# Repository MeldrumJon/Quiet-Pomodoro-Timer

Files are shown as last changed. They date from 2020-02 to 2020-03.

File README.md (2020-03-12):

# Visual-Timer

Shows timer progress on screen.  Flashes a bright LED when the timer expires 
instead of ringing or vibrating.  Useful for time management in quiet offices 
or libraries.

Visual Timer
Time's Up

## Parts

- [16x2 Reflective LCD Character Display](https://www.mouser.com/ProductDetail/668-S16204XRGHS10B)
- ATMega328p-PU
    - With fuses set to use internal 8MHz clock (use Makefile: `make fuses`)
- [Rotary encoder with push button switch](https://www.mouser.com/ProductDetail/652-PEC11R4315KS0012)
- 2x [Bright LEDs](https://www.mouser.com/ProductDetail/78-TLHK46Q1R2)
- 10uF electrolytic capacitor
- 3x 0.1uF ceramic capacitors
- 2x 220 ohm resistors
- 10k ohm potentiometer
- Breakaway headers
- Battery holder for 3xAA or 3xAAA batteries

## Tools

- AVR ISP Programmer or [arduinoISP](https://www.arduino.cc/en/tutorial/arduinoISP)
- USB to TTY serial adapter for debugging.

## Schematic

Visual Timer's schematic

## Setup

1. Install the AVR-GCC toolchain (and update your `PATH` variable, if necessary)
2. Connect the AVR ISP programmer pins to the ISP header on the PCB.
3. Connect the ATMega328p's TX pin to RX on the TTY serial adapter (optional)
4. Update the `program` and `fuses` recipes in the makefile to use your AVR 
ISP programmer.
5. Update the `serial` recipe in the makefile to use your USB to TTY serial 
adapter.
6. Run `make fuses` to set the fuses on the ATMega328p.
    - If the ATMega328p was previously set to use an external clock or crystal 
    oscillator, an external clock or crystal oscillator will be needed to set 
    the fuses.

## Programming

Run `make program` to program the ATMega328p.

## PCB

KiCAD files are in [the `hardware` Folder](./hardware).

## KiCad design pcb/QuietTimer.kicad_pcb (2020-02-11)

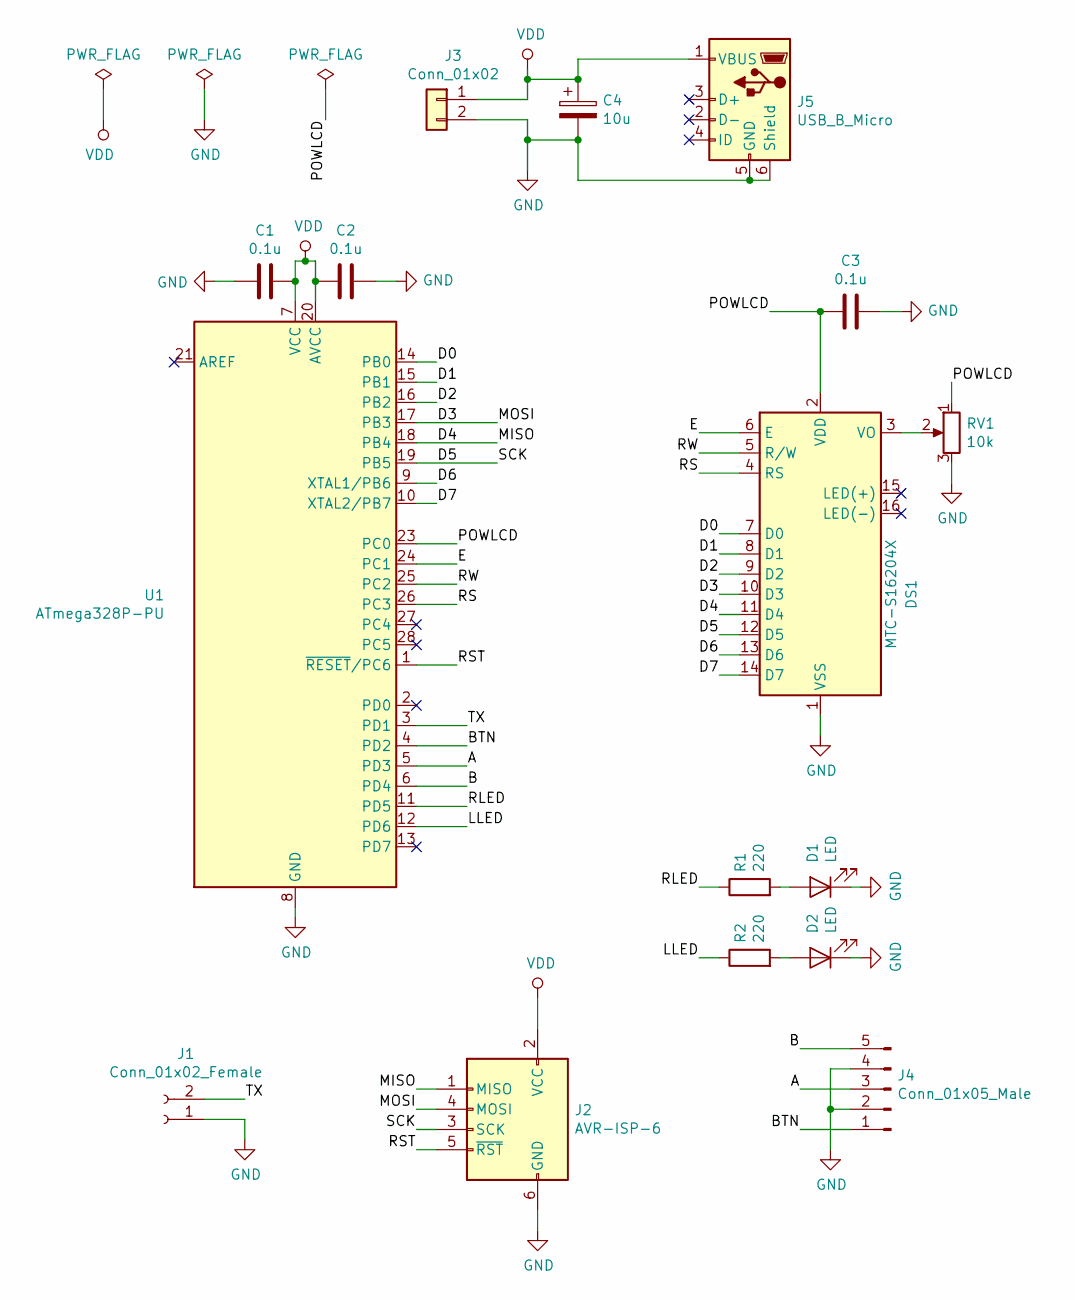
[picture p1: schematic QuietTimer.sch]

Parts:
C1, C2, C3: 0.1u; C_Disc_D5.0mm_W2.5mm_P2.50mm
C4: 10u; CP_Radial_D5.0mm_P2.00mm
D1, D2: LED; LED_D3.0mm
DS1: MTC-S16204X; MTC-16204X
J1: Conn_01x02_Female; PinSocket_1x02_P2.54mm_Vertical
J2: AVR-ISP-6; IDC-Header_2x03_P2.54mm_Vertical
J3: Conn_01x02; SolderWirePad_1x02_P3.81mm_Drill0.8mm
J4: Conn_01x05_Male; PinHeader_1x05_P2.54mm_Vertical
J5: USB_B_Micro; USB_Micro-B_Wuerth_614105150721_Vertical
R1, R2: 220; R_Axial_DIN0207_L6.3mm_D2.5mm_P2.54mm_Vertical
RV1: 10k; Potentiometer_Piher_PT-6-V_Vertical_Hole
U1: ATmega328P-PU; DIP-28_W7.62mm

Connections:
/A: J4.3, U1.5 (PD3)
/B: J4.5, U1.6 (PD4)
/BTN: J4.1, U1.4 (PD2)
/D0: DS1.7 (D0), U1.14 (PB0)
/D1: DS1.8 (D1), U1.15 (PB1)
/D2: DS1.9 (D2), U1.16 (PB2)
/D3: DS1.10 (D3), J2.4 (MOSI), U1.17 (PB3)
/D4: DS1.11 (D4), J2.1 (MISO), U1.18 (PB4)
/D5: DS1.12 (D5), J2.3 (SCK), U1.19 (PB5)
/D6: DS1.13 (D6), U1.9 (XTAL1/PB6)
/D7: DS1.14 (D7), U1.10 (XTAL2/PB7)
/E: DS1.6 (E), U1.24 (PC1)
/LLED: R2.1, U1.12 (PD6)
/POWLCD: C3.2, DS1.2 (VDD), RV1.1, U1.23 (PC0)
/RLED: R1.1, U1.11 (PD5)
/RS: DS1.4 (RS), U1.26 (PC3)
/RST: J2.5 (~RST), U1.1 (~RESET~/PC6)
/RW: DS1.5 (R/W), U1.25 (PC2)
/TX: J1.2, U1.3 (PD1)
GND: C1.2, C2.1, C3.1, C4.2, D1.1 (K), D2.1 (K), DS1.1 (VSS), J1.1, J2.6 (GND), J3.2, J4.2, J4.4, J5.5 (GND), J5.6 (Shield), RV1.3, U1.8 (GND), U1.22 (GND)
unnamed: D1.2 (A), R1.2
unnamed: D2.2 (A), R2.2
unnamed: DS1.3 (VO), RV1.2
VDD: C1.1, C2.2, C4.1, J2.2 (VCC), J3.1, J5.1 (VBUS), U1.7 (VCC), U1.20 (AVCC)

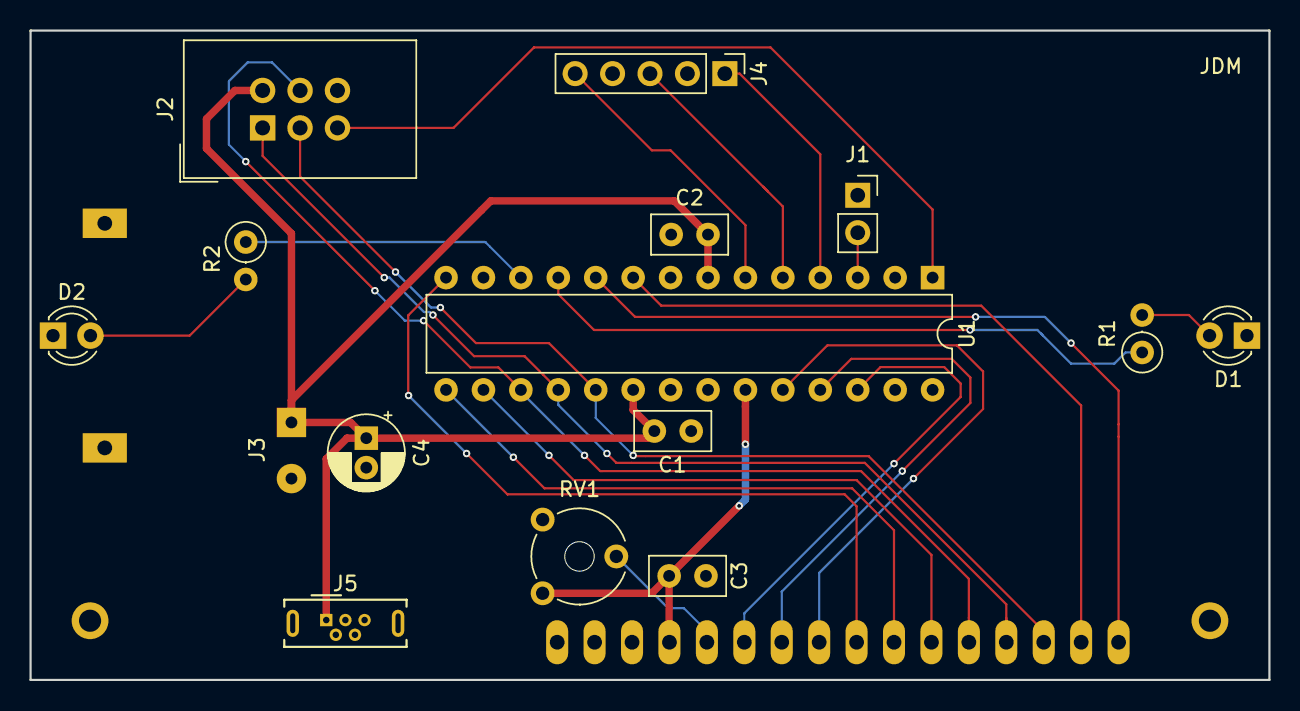
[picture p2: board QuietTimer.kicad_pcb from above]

Board: 2 copper layers, 84.1 x 44.1 mm, 16 parts (1 on the bottom side), 24 nets.

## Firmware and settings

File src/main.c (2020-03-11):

#include <avr/io.h>
#include <avr/interrupt.h>
#include <avr/power.h>
#include <avr/sleep.h>
#include <util/delay.h>
#include <stdio.h>
#include "controller.h"
#include "lcd.h"
#include "btn.h"
#include "encoder.h"
#include "timer.h"

int main(void) {
    // Power Saving
    ADCSRA = 0; // Disable ADC
    power_all_disable();
    power_timer2_enable();

    // Output low
    DDRB = 0xFF;
    DDRC = 0xFF;
    DDRD = 0xFF;
    PORTB = 0x00;
    PORTC = 0x00;
    PORTD = 0x00;

    btn_enable();
    encoder_enable();
    timer_enable();

    //power_usart0_enable();
    //usart_init();
    //stdout = &uart_stream;
    //printf("Hello world!\r\n");

    for (;;) {
        if (btn_intrpted()) {
            controller_wake();
        }

        if (btn_pressed()) {
            controller_press();
        }

        if (btn_longpressed()) {
            controller_longpress();
        }

        int8_t delta = encoder_delta();
        if (delta) {
            controller_rotate(delta);
        }

        if (timer_intrpted()) {
            btn_tick();
            controller_tick();
        }

        // Low power sleep
        if (controller_inDeepSleep()) {
            set_sleep_mode(SLEEP_MODE_PWR_DOWN);
        }
        else {
            set_sleep_mode(SLEEP_MODE_PWR_SAVE);
        }
        cli();
        sleep_enable();
        sei();
        sleep_cpu();
        sleep_disable();
    }
}

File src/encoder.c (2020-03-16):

#include "encoder.h"
#include <stdint.h>
#include <avr/interrupt.h>
#include <avr/io.h>

// Mask for the register that handles the A/B pin input
#define ROTARY_A_DMASK 0x10
#define ROTARY_B_DMASK 0x08
#define PCINT2_EN_MASK 0x04

// Contains the previous state of the encoder (bits[7:2]: unused)
// bit[1]: old state of A
// bit[0]: old state of B
volatile static uint8_t state = 0;

// Contains the change in encoder position since the last read.
volatile static int8_t g_delta = 0;

/**
 * This ISR is called when one of the pins on the rotary encoder change levels.
 * <code>
 *                     _______         _______       
 *            A ______|       |_______|       |______ A
 * CCW <---        _______         _______         __      --> CW
 *            B __|       |_______|       |_______|   B
 * </code>
 * <p>
 * Variable s retrieves the old state (stored in bits 1 and 0) and reads the new state
 * (stored in bits 3 and 2).  The table below shows how to calculate the change in the
 * encoder position from the previous and current state.
 * </p>
 * <code>
 *	    new	new old	old
 * case	 B	 A	 B	 A 	 Result
 * ---- --- --- --- ---  ------
 *   0   0	 0	 0	 0	 no movement
 *   1   0	 0	 0	 1	 +1
 *   2   0	 0	 1	 0	 -1
 *   3   0	 0	 1	 1	 +2  (assume A's edges only)
 *   4   0	 1	 0	 0	 -1
 *   5   0	 1	 0	 1	 no movement
 *   6   0	 1	 1	 0	 -2  (assume A's edges only)
 *   7   0	 1	 1	 1	 +1
 *   8   1	 0	 0	 0	 +1
 *   9   1	 0	 0	 1	 -2  (assume A's edges only)
 *  10   1	 0	 1	 0	 no movement
 *  11   1	 0	 1	 1	 -1
 *  12   1	 1	 0	 0	 +2  (assume A's edges only)
 *  13   1	 1	 0	 1	 -1
 *  14   1	 1	 1	 0	 +1
 *  15   1	 1	 1	 1	 no movement
 * </code>
 */
int8_t delta_lut[16] = {
    0,
    +1,
    -1,
    +2,
    -1,
    0,
    -2,
    +1,
    +1,
    -2,
    0,
    -1,
    +2,
    -1,
    +1,
    0
};

ISR(PCINT2_vect, ISR_BLOCK) {
	uint8_t s = state;
	if (PIND & ROTARY_A_DMASK) { s |= 0x4; }
	if (PIND & ROTARY_B_DMASK) { s |= 0x8; }
	g_delta += delta_lut[s];
	state = (s >> 2);
}

/**
 * Enables pin change interrupts for the rotary encoder.
 */
void encoder_enable(void) {
	// Setup pin change interrupts (encoder)
	cli();
	DDRD &= ~(ROTARY_A_DMASK | ROTARY_B_DMASK); // Set pins as input
	PORTD |= (ROTARY_A_DMASK | ROTARY_B_DMASK); // Activate pull-ups
	PCICR |= PCINT2_EN_MASK; // Enable pin-change interrupt PCINT2
	PCMSK2 |= (ROTARY_A_DMASK | ROTARY_B_DMASK); // Enable interrupts for pins
	sei();
}

void encoder_disable(void) {
	cli();
	DDRD |= (ROTARY_A_DMASK | ROTARY_B_DMASK); // Set pins as output
	PORTD &= ~(ROTARY_A_DMASK | ROTARY_B_DMASK); // Drive pins low 
	PCICR &= ~(PCINT2_EN_MASK); // Disable pin-change interrupt
	PCMSK2 &= ~(ROTARY_A_DMASK | ROTARY_B_DMASK); // Disable interrupts for the pins
	sei();
}

/**
 * Returns the number of detents moved since the last time encoder_delta was called.
 *
 * <p>
 * The global variable g_delta actually increments/decrements 4 times between detents.
 * This function rounds to the nearest detent.
 * </p>
 * <code>
 * [0, 1] -> 0
 * [2, 3, 4, 5] -> 4
 * </code>
 *
 * @return The number of detents turned since last call.  Negative values indicate
 * counter-clockwise turning.  Positive values indicate clockwise turning.
 */
int8_t encoder_delta(void) {
	static int8_t old_pos = 0; // Save the old position for the next call
	int8_t zeroed_delta;
	int8_t pos;

	cli();
	pos = g_delta;
	// Zero g_delta, except for the lower digits to avoid adding a weird offset if this 
	// function is called while the encoder is partway turned.
	g_delta = zeroed_delta = g_delta & 0x3;
	sei();

	pos = (pos + 2) >> 2; // Round position to nearest detent.
	int8_t delta = (pos - old_pos);
	old_pos = (zeroed_delta + 2) >> 2; // Round "cleared" g_delta to nearest detent

	return delta;
}

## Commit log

2020-02-09 Beginning of PCB
    [QuietTimer.kicad_pcb, QuietTimer.sch]
2020-02-10 Finish Custom Footprints
    [QuietTimer.sch]
2020-02-10 Finished Schematic
    [QuietTimer.sch]
2020-02-11 Finished PCB
    [QuietTimer.kicad_pcb, QuietTimer.sch]
2020-03-16 Optimize LCD Write, Add Calibration
